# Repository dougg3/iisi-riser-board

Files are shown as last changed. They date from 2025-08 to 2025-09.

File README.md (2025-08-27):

# Macintosh IIsi power supply riser board replica

This is a replica of the daughterboard found in the Apple/Sony Macintosh IIsi APS-06 power supply. The part number printed on the original board is AP41S. This PCB often suffers from severe corrosion damage due to electrolytic capacitor leakage, so this project aims to provide you with a way to replace it with a brand new PCB.

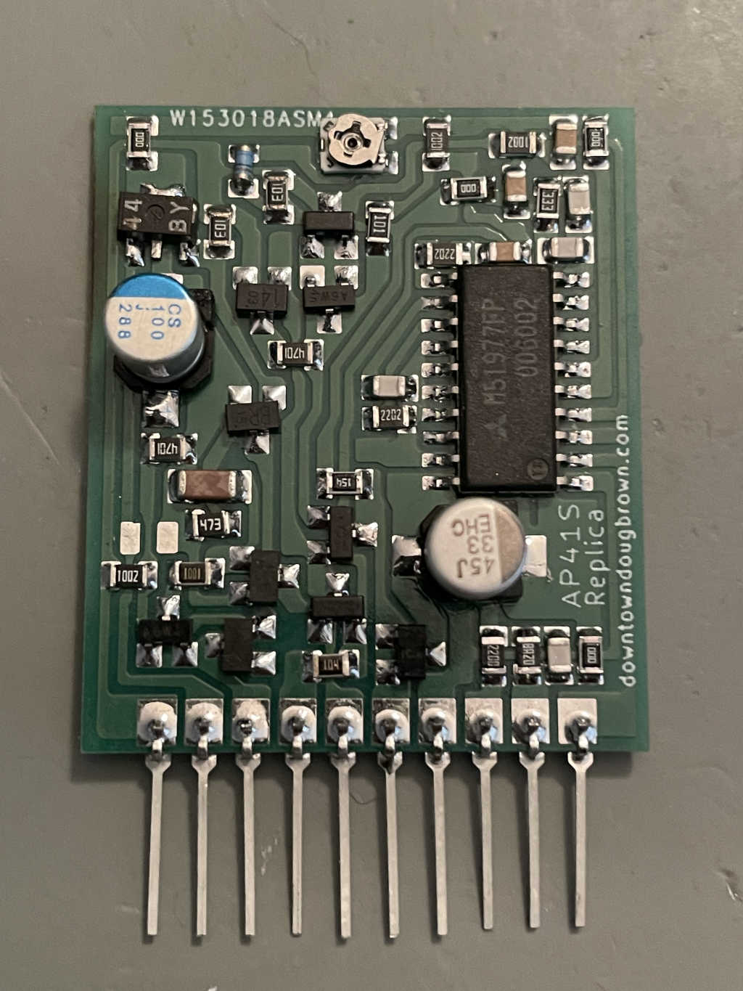
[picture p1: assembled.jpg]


To aid with reverse engineering, all of the components were removed from the board and inspected out of circuit. I used pictures of the bare board ([top](barepcb_top.jpg?raw=true), [bottom](barepcb_bottom.jpg?raw=true)) to draw a replica design. The [Bomarc schematics](https://www.macdat.net/files/pdf/apple/schematics/bomarc/mac_iisi.pdf) were a huge help with part identification and understanding the circuit. However, those schematics did have a few mistakes, which I have corrected in my schematics and BOM. My replica design has been successfully used to build a brand new board with all new components except for the two obsolete ICs.

## Schematics

[Here is a link to the schematics in PDF format](iisi-riser-board.pdf?raw=true).

## Build Notes

[Here is an image that shows the names that I arbitrarily gave each component, along with their values](placement.png?raw=true). It may help if you decide to build one yourself.

The trimpot is used to adjust the voltage. If you build one yourself, it may be prudent to test the power supply with a dummy load connected and get the trimpot adjusted properly before trying to use it in an actual Mac IIsi.

## BOM

[Here is the bill of materials in CSV format](iisi-riser-board.csv). All of the parts with the exception of the two obsolete Mitsubishi/Renesas ICs can be purchased brand new from Digi-Key. Note that you need to purchase ten of the leadframe pins for the edge connector.

## Gerbers

[Here is a link to the gerbers](gerbers/) if you want to have boards made yourself. I ordered them as 30.5x36mm, single layer, 0.8 mm thickness, HASL, and solder mask and silkscreen only on one side.

## Purchasing

For convenience, I plan on building some of these up for sale to recoup my costs on this project. I also will save some bare PCBs you can purchase if you just want to move all of your components over from your original corrosion-damaged PCB. Stay tuned for more info on how I will sell these.

## KiCad Design Notes

- The trace widths were very strange on this board, so I just used polygon copper fills to redraw them all. I also manually tweaked each pad's size to bring everything close to the original design.
- The board fails some DRC checks which I have added as exclusions.
- The three GND-to-GND 0-ohm resistors cause three "Unconnected Items" warnings in the DRC. These can be safely ignored.

## Differences from Bomarc reverse-engineered schematics

- The resistor labeled as 8200 ohms in Bomarc's schematic is really 8.2 ohms.
- The chip marked as `44` is really a Mitsubishi/Renesas M51944BML, not a transistor. It's a voltage detector/reset IC.
- The diode marked as `=B` is a Schottky diode; I opted to use the onsemi SB05-05C, which is also marked as `B`.
- I have identified all of the ceramic capacitor values using an LCR meter.
- Pin 9 of the edge connector has been correctly labeled as GND.

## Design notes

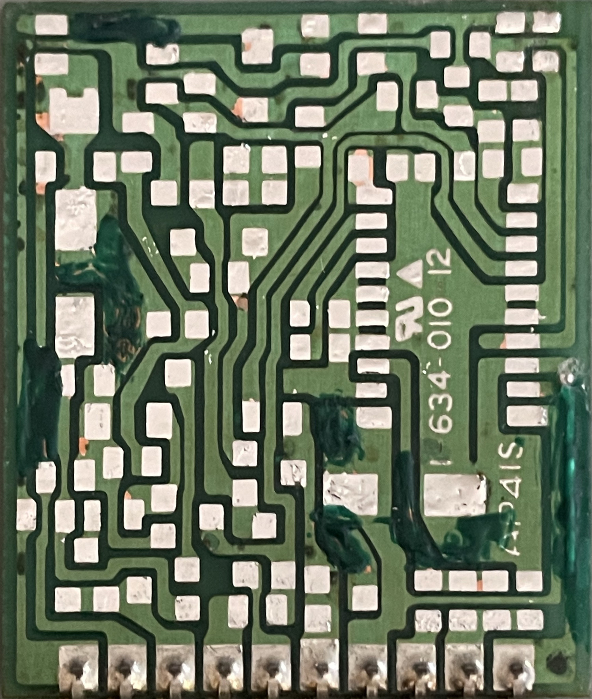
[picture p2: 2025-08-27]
barepcb_top.jpg

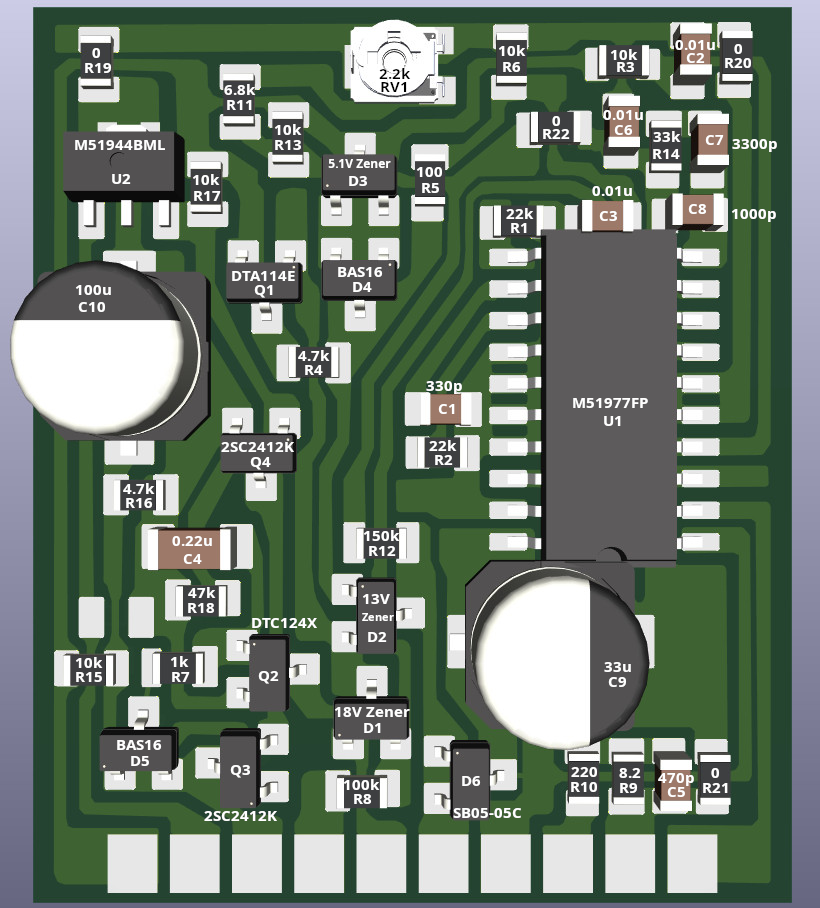
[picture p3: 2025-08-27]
placement.png

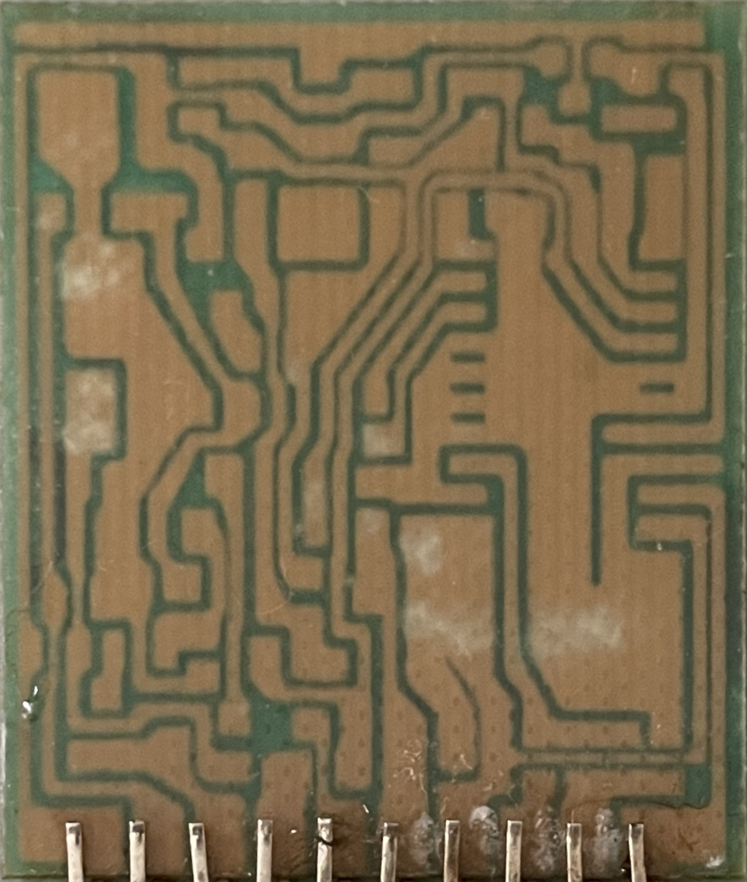
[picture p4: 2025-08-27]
barepcb_bottom.jpg

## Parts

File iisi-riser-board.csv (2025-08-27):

Reference | Qty | Value | DNP | Exclude from BOM | Exclude from Board | Footprint | Datasheet | Digi-Key Part
C1 | 1 | 330pF |  |  |  | iisi-riser-board:C_0805_2012Metric |  | 399-C0805C331J5GACTUCT-ND
C2,C3,C6 | 3 | 0.01uF |  |  |  | iisi-riser-board:C_0805_2012Metric |  | 399-C0805C103K5RACTUCT-ND
C4 | 1 | 0.22uF |  |  |  | Capacitor_SMD:C_1206_3216Metric |  | 445-2283-1-ND
C5 | 1 | 470pF |  |  |  | iisi-riser-board:C_0805_2012Metric |  | 311-1119-1-ND
C7 | 1 | 3300pF |  |  |  | iisi-riser-board:C_0805_2012Metric |  | 399-C0805C332J5GACTUCT-ND
C8 | 1 | 1000pF |  |  |  | iisi-riser-board:C_0805_2012Metric |  | 399-C0805C102J5GACTUCT-ND
C9 | 1 | 33uF |  |  |  | iisi-riser-board:CP_Elec |  | 565-4768-1-ND
C10 | 1 | 100uF |  |  |  | iisi-riser-board:CP_Elec |  | 493-3967-1-ND
C11 | 1 | ? | DNP |  |  | iisi-riser-board:C_0805_2012Metric
D1 | 1 | 18V |  |  |  | iisi-riser-board:SC-59-Diode | ~ | MMBZ5248B-FDICT-ND
D2 | 1 | 13V |  |  |  | iisi-riser-board:SC-59-Diode | ~ | BZX84C13-FDICT-ND
D3 | 1 | 5.1V |  |  |  | iisi-riser-board:SC-59-Diode | ~ | SZBZX84C5V1LT3GOSCT-ND
D4,D5 | 2 | BAS16 |  |  |  | iisi-riser-board:SC-59-Diode | ~ | 1727-2887-1-ND
D6 | 1 | SB05-05C-TB-E |  |  |  | iisi-riser-board:SC-59-Diode | ~ | SB05-05C-TB-EOSCT-ND
J1 | 1 | Conn_01x10_Pin |  |  |  | iisi-riser-board:EdgeConnector10 | ~ | A122175CT-ND
Q1 | 1 | DTA114E |  |  |  | iisi-riser-board:SOT-346-Rohm |  | DTA114EKAT146CT-ND
Q2 | 1 | DTC124X |  |  |  | iisi-riser-board:SOT-346-Rohm |  | DTC124XKAT146CT-ND
Q3,Q4 | 2 | 2SC2412K |  |  |  | iisi-riser-board:SOT-346-Rohm | ~ | 2SC2412KT146RCT-ND
R1,R2 | 2 | 22k |  |  |  | iisi-riser-board:R_0805_2012Metric | ~ | A129765CT-ND
R3,R6,R13,R15,R17 | 5 | 10k |  |  |  | iisi-riser-board:R_0805_2012Metric | ~ | A129761CT-ND
R4,R16 | 2 | 4.7k |  |  |  | iisi-riser-board:R_0805_2012Metric | ~ | A129757CT-ND
R5 | 1 | 100 |  |  |  | iisi-riser-board:R_0805_2012Metric | ~ | P100DACT-ND
R7 | 1 | 1k |  |  |  | iisi-riser-board:R_0805_2012Metric | ~ | A129749CT-ND
R8 | 1 | 100k |  |  |  | iisi-riser-board:R_0805_2012Metric | ~ | A129773CT-ND
R9 | 1 | 8.2 |  |  |  | iisi-riser-board:R_0805_2012Metric | ~ | 13-RC0805FR-078R2LCT-ND
R10 | 1 | 220 |  |  |  | iisi-riser-board:R_0805_2012Metric | ~ | A129741CT-ND
R11 | 1 | 6.8k |  |  |  | iisi-riser-board:R_0805_2012Metric | ~ | A127026CT-ND
R12 | 1 | 150k |  |  |  | iisi-riser-board:R_0805_2012Metric | ~ | P150KACT-ND
R14 | 1 | 33k |  |  |  | iisi-riser-board:R_0805_2012Metric | ~ | P33KDACT-ND
R18 | 1 | 47k |  |  |  | iisi-riser-board:R_0805_2012Metric | ~ | 311-47KARCT-ND
R19,R20,R21,R22 | 4 | 0 |  |  |  | iisi-riser-board:R_0805_2012Metric | ~ | P0.0ACT-ND
RV1 | 1 | 2.2k |  |  |  | Potentiometer_SMD:Potentiometer_Bourns_TC33X_Vertical | ~ | 118-TC33X-1-222ECT-ND
U1 | 1 | M51977FP |  |  |  | iisi-riser-board:SO-20_5.3x12.6mm_P1.27mm
U2 | 1 | M51944BML |  |  |  | Package_TO_SOT_SMD:SOT-89-3

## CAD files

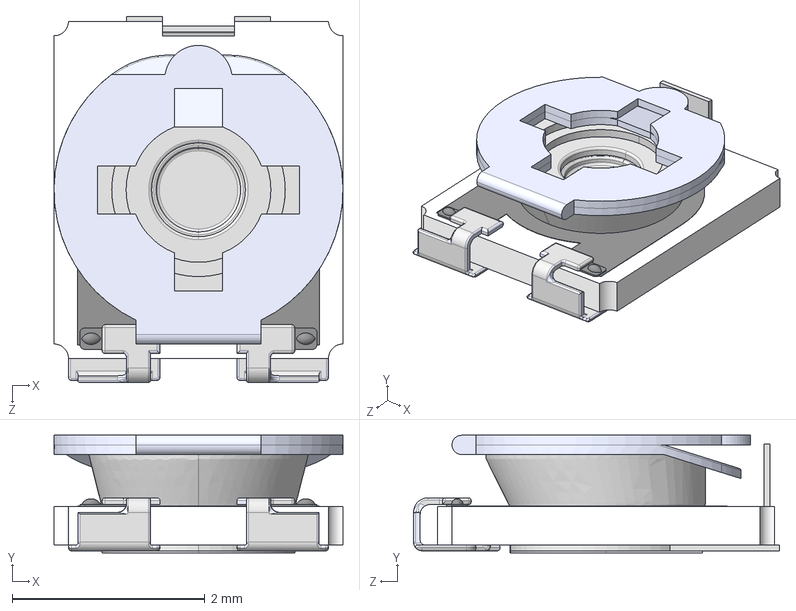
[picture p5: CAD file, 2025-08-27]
TC33X-2-202G.stp
3.00 x 1.22 x 3.80 mm

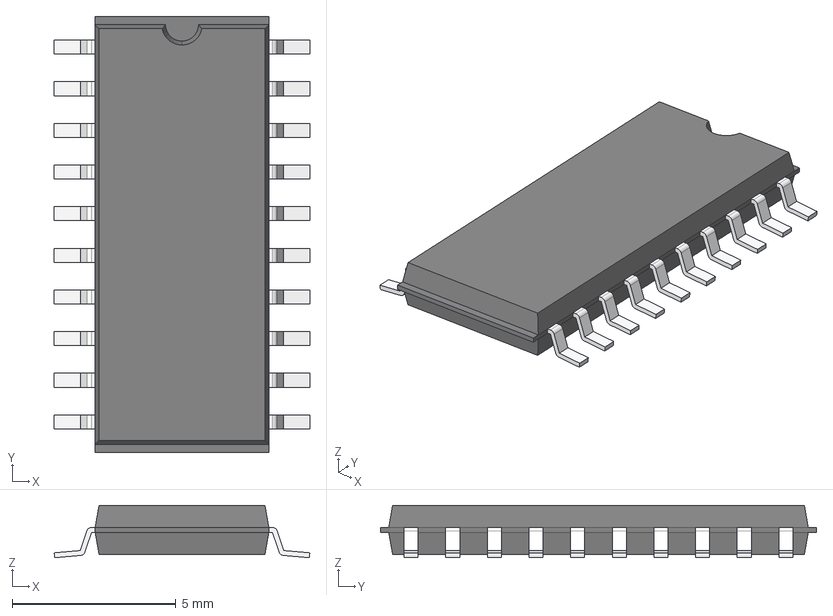
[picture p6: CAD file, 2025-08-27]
SOP20_z90.stp
7.80 x 13.3 x 1.60 mm

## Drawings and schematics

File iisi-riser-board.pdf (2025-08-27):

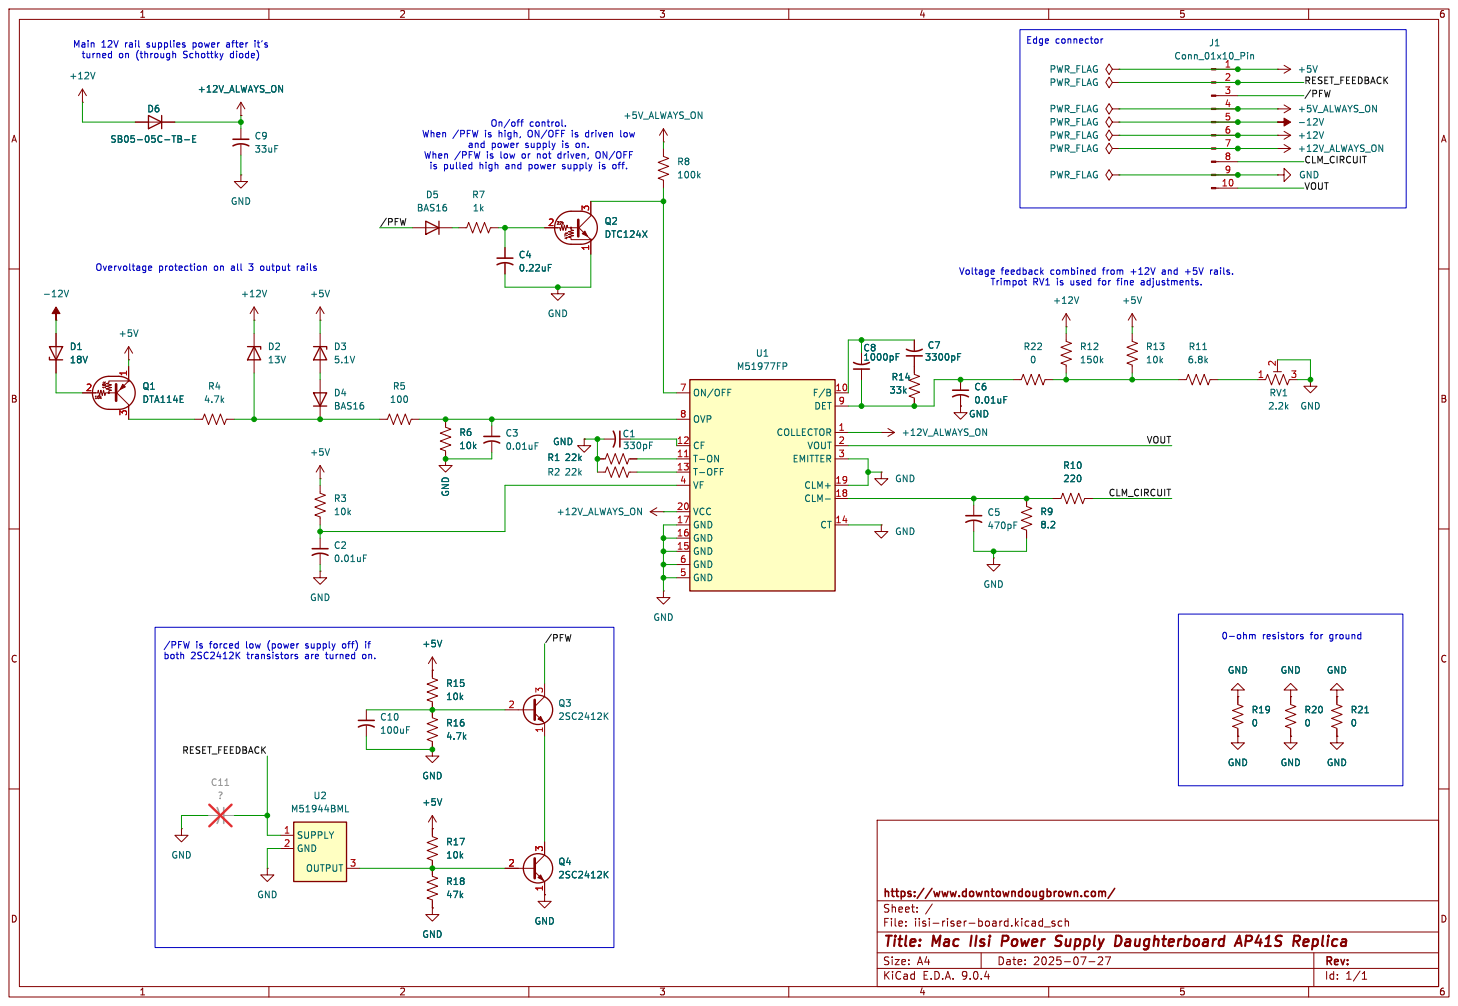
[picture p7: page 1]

and power supply is on. When /PFW is low or not driven, ON/OFF

Id: 1/1 Title: Mac IIsi Power Supply Daughterboard AP41S Replica

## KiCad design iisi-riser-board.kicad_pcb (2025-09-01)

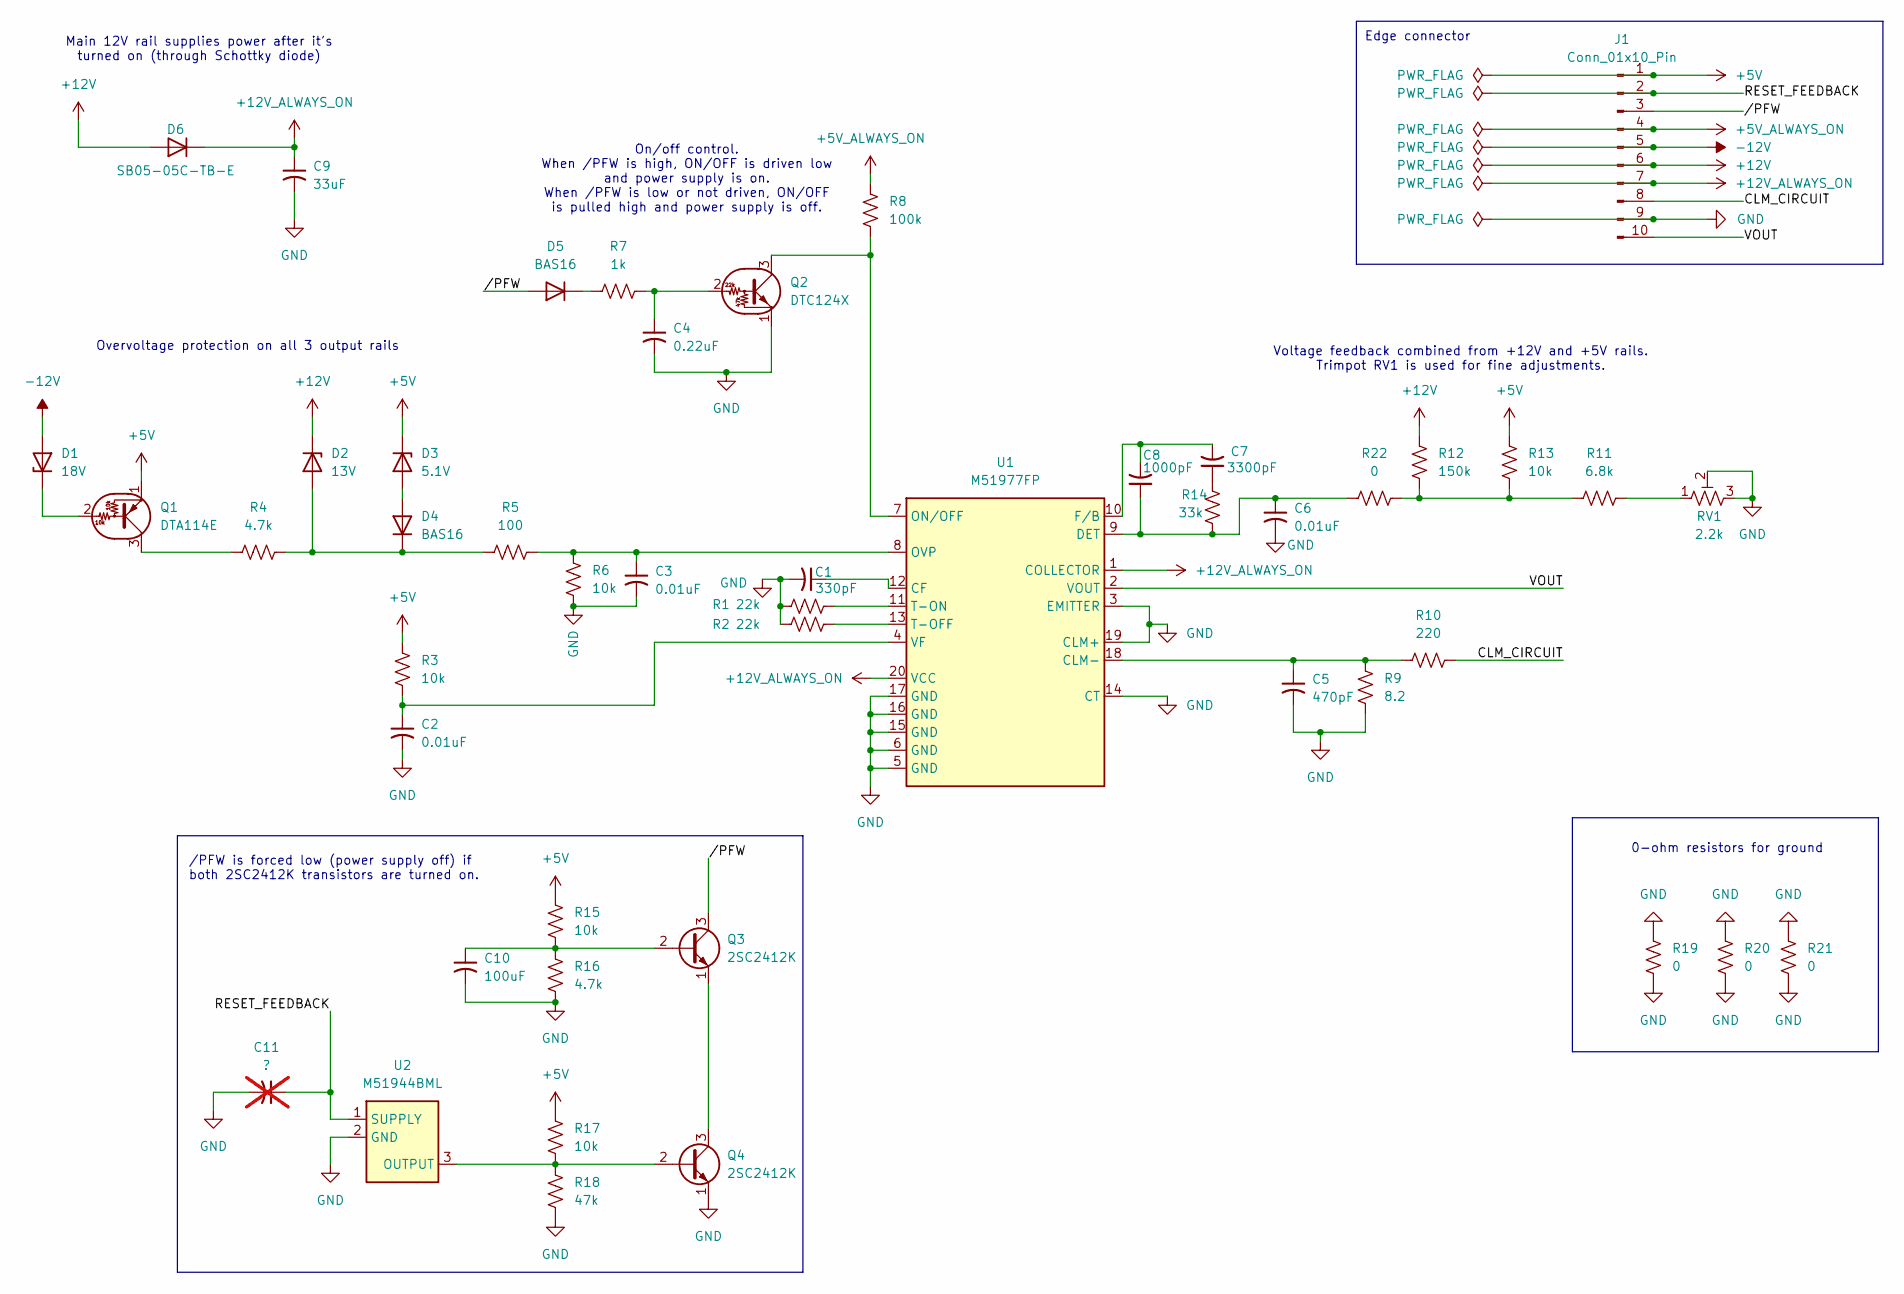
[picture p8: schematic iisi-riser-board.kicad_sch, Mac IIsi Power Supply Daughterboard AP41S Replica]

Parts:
C1: 330pF; C_0805_2012Metric; Digi-Key Part 399-C0805C331J5GACTUCT-ND
C2, C3, C6: 0.01uF; C_0805_2012Metric; Digi-Key Part 399-C0805C103K5RACTUCT-ND
C4: 0.22uF; C_1206_3216Metric; Digi-Key Part 445-2283-1-ND
C5: 470pF; C_0805_2012Metric; Digi-Key Part 311-1119-1-ND
C7: 3300pF; C_0805_2012Metric; Digi-Key Part 399-C0805C332J5GACTUCT-ND
C8: 1000pF; C_0805_2012Metric; Digi-Key Part 399-C0805C102J5GACTUCT-ND
C9: 33uF; CP_Elec; Digi-Key Part 565-4768-1-ND
C10: 100uF; CP_Elec; Digi-Key Part 493-3967-1-ND
C11: ?; C_0805_2012Metric; not fitted
D1: 18V; SC-59-Diode; Digi-Key Part MMBZ5248B-FDICT-ND
D2: 13V; SC-59-Diode; Digi-Key Part BZX84C13-FDICT-ND
D3: 5.1V; SC-59-Diode; Digi-Key Part SZBZX84C5V1LT3GOSCT-ND
D4, D5: BAS16; SC-59-Diode; Digi-Key Part 1727-2887-1-ND
D6: SB05-05C-TB-E; SC-59-Diode; Digi-Key Part SB05-05C-TB-EOSCT-ND
J1: Conn_01x10_Pin; EdgeConnector10; Digi-Key Part A122175CT-ND
Q1: DTA114E; SOT-346-Rohm; Digi-Key Part DTA114EKAT146CT-ND
Q2: DTC124X; SOT-346-Rohm; Digi-Key Part DTC124XKAT146CT-ND
Q3, Q4: 2SC2412K; SOT-346-Rohm; Digi-Key Part 2SC2412KT146RCT-ND
R1, R2: 22k; R_0805_2012Metric; Digi-Key Part A129765CT-ND
R3, R6, R13, R15, R17: 10k; R_0805_2012Metric; Digi-Key Part A129761CT-ND
R4, R16: 4.7k; R_0805_2012Metric; Digi-Key Part A129757CT-ND
R5: 100; R_0805_2012Metric; Digi-Key Part P100DACT-ND
R7: 1k; R_0805_2012Metric; Digi-Key Part A129749CT-ND
R8: 100k; R_0805_2012Metric; Digi-Key Part A129773CT-ND
R9: 8.2; R_0805_2012Metric; Digi-Key Part 13-RC0805FR-078R2LCT-ND
R10: 220; R_0805_2012Metric; Digi-Key Part A129741CT-ND
R11: 6.8k; R_0805_2012Metric; Digi-Key Part A127026CT-ND
R12: 150k; R_0805_2012Metric; Digi-Key Part P150KACT-ND
R14: 33k; R_0805_2012Metric; Digi-Key Part P33KDACT-ND
R18: 47k; R_0805_2012Metric; Digi-Key Part 311-47KARCT-ND
R19, R20, R21, R22: 0; R_0805_2012Metric; Digi-Key Part P0.0ACT-ND
RV1: 2.2k; Potentiometer_Bourns_TC33X_Vertical; Digi-Key Part 118-TC33X-1-222ECT-ND
U1: M51977FP; SO-20_5.3x12.6mm_P1.27mm
U2: M51944BML; SOT-89-3

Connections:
+5V: D3.1 (K), J1.1, Q1.1 (E), R3.1, R13.1, R15.1, R17.1
+5V_ALWAYS_ON: J1.4, R8.1
+12V: D2.1 (K), D6.2 (A), J1.6, R12.1
+12V_ALWAYS_ON: C9.1, D6.1 (K), J1.7, U1.1 (COLLECTOR), U1.20 (VCC)
-12V: D1.2 (A), J1.5
/CLM_CIRCUIT: J1.8, R10.1
/RESET_FEEDBACK: C11.1, J1.2, U2.1 (SUPPLY)
/VOUT: J1.10, U1.2 (VOUT)
//PFW: D5.2 (A), J1.3, Q3.3 (C)
GND: C1.2, C2.2, C3.2, C4.2, C5.2, C6.2, C9.2, C10.2, C11.2, J1.9, Q2.1 (E), Q4.1 (E), R1.1, R2.1, R6.1, R9.1, R16.2, R18.2, R19.1, R19.2, R20.1, R20.2, R21.1, R21.2, RV1.2, RV1.3, U1.3 (EMITTER), U1.5 (GND), U1.6 (GND), U1.14 (CT), U1.15 (GND), U1.16 (GND), U1.17 (GND), U1.19 (CLM+), U2.2 (GND)
unnamed: C7.1, R14.2
unnamed: D1.1 (K), Q1.2 (B)
unnamed: D2.2 (A), D4.1 (K), R4.2, R5.1
unnamed: D3.2 (A), D4.2 (A)
unnamed: D5.1 (K), R7.1
unnamed: Q1.3 (C), R4.1
unnamed: C4.1, Q2.2 (B), R7.2
unnamed: Q2.3 (C), R8.2, U1.7 (ON/OFF)
unnamed: C10.1, Q3.2 (B), R15.2, R16.1
unnamed: Q3.1 (E), Q4.3 (C)
unnamed: Q4.2 (B), R17.2, R18.1, U2.3 (OUTPUT)
unnamed: R11.1, RV1.1
unnamed: R11.2, R12.2, R13.2, R22.1
unnamed: C1.1, U1.12 (CF)
unnamed: C5.1, R9.2, R10.2, U1.18 (CLM-)
unnamed: C6.1, C8.1, R14.1, R22.2, U1.9 (DET)
unnamed: C7.2, C8.2, U1.10 (F/B)
unnamed: C3.1, R5.2, R6.2, U1.8 (OVP)
unnamed: R2.2, U1.13 (T-OFF)
unnamed: R1.2, U1.11 (T-ON)
unnamed: C2.1, R3.2, U1.4 (VF)

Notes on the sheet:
0-ohm resistors for ground
On/off control. When /PFW is high, ON/OFF is driven low and power supply is on. When /PFW is low or not driven, ON/OFF is pulled high and power supply is off.
Overvoltage protection on all 3 output rails
Voltage feedback combined from +12V and +5V rails. Trimpot RV1 is used for fine adjustments.
/PFW is forced low (power supply off) if both 2SC2412K transistors are turned on.
Edge connector
Main 12V rail supplies power after it's turned on (through Schottky diode)

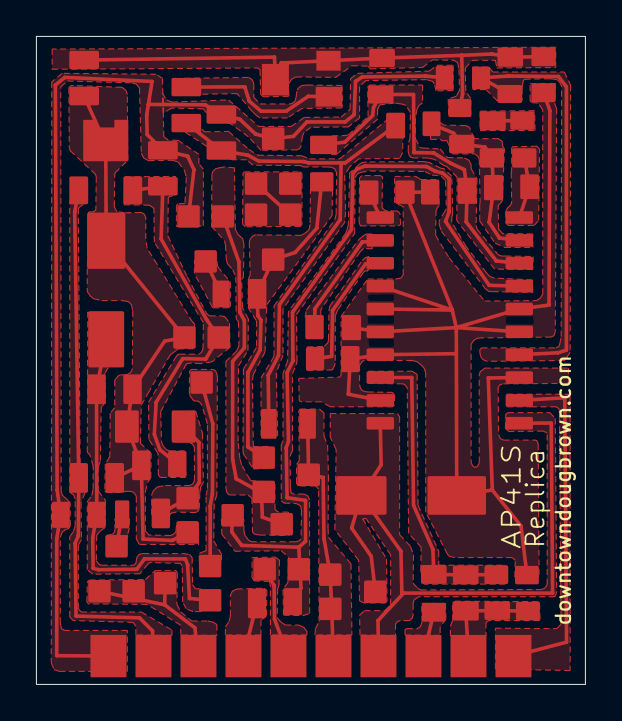
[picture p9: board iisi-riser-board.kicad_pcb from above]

Board: 2 copper layers, 30.5 x 36.0 mm, 47 parts (0 on the bottom side), 31 nets.

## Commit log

2025-08-27 Initial commit of IIsi power supply daughterboard replica design
    [SOP20_z90.stp, TC33X-2-202G.stp, iisi-riser-board.kicad_pcb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]
2025-08-27 Add gerbers for replica PCB
    [iisi-riser-board-Edge_Cuts.gbr, iisi-riser-board-F_Cu.gbr, iisi-riser-board-F_Mask.gbr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]
2025-08-27 Add schematic PDF
2025-08-27 Add Digi-Key part numbers for everything that is brand new
    [iisi-riser-board.kicad_sch]
2025-08-27 Add BOM
    [iisi-riser-board.csv]
2025-08-27 Add picture of assembled board
2025-09-01 Add big capacitors to paste layer
    I left them out initially because I was using hot air and manually
    soldering those two caps on afterward. With reflow, there's no reason to
    leave the caps out from the solder paste.
    [iisi-riser-board.kicad_pcb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]
